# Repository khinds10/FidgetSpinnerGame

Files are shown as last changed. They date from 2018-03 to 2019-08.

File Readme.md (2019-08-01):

# Fidget Spinner Game - Cool Fidget Spinner Game for my son's Science Fair
Kids love this one, who can spin the longest?  Who can spin the fastest? Find out using this project!

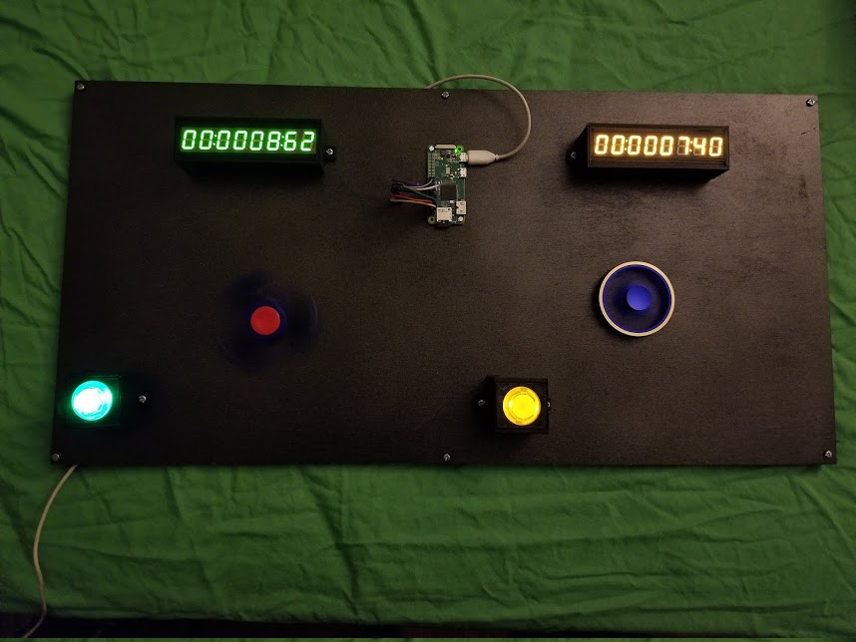
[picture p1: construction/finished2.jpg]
Finished


#### Flashing RaspberriPi Hard Disk / Install Required Software (Using Ubuntu Linux)

Download "RASPBIAN JESSIE LITE"
https://www.raspberrypi.org/downloads/raspbian/

**Create your new hard disk for Fidget Spinner Game**
>Insert the microSD to your computer via USB adapter and create the disk image using the `dd` command
>
> Locate your inserted microSD card via the `df -h` command, unmount it and create the disk image with the disk copy `dd` command
> 
> $ `df -h`
> */dev/sdb1       7.4G   32K  7.4G   1% /media/XXX/1234-5678*
> 
> $ `umount /dev/sdb1`
> 
> **Caution: be sure the command is completely accurate, you can damage other disks with this command**
> 
> *if=location of RASPBIAN JESSIE LITE image file*
> *of=location of your microSD card*
> 
> $ `sudo dd bs=4M if=/path/to/raspbian-jessie-lite.img of=/dev/sdb`
> *(note: in this case, it's /dev/sdb, /dev/sdb1 was an existing factory partition on the microSD)*

**Setting up your RaspberriPi**

*Insert your new microSD card to the raspberrypi and power it on with a monitor connected to the HDMI port*

Login
> user: **pi**
>
> pass: **raspberry**

Change your account password for security
>`sudo passwd pi`

Enable RaspberriPi Advanced Options
>`sudo raspi-config`

Choose:
`1 Expand File System`

`9 Advanced Options`
>`A2 Hostname`
>*change it to "FidgetSpinner"*
>
>`A4 SSH`
>*Enable SSH Server*
>
>`A7 I2C`
>*Enable i2c interface*

**Enable the English/US Keyboard**

>`sudo nano /etc/default/keyboard`

> Change the following line:
>`XKBLAYOUT="us"`

**Reboot PI for Keyboard layout changes / file system resizing to take effect**
>$ `sudo shutdown -r now`

**Auto-Connect to your WiFi**

>`sudo nano /etc/wpa_supplicant/wpa_supplicant.conf`

Add the following lines to have your raspberrypi automatically connect to your home WiFi
*(if your wireless network is named "linksys" for example, in the following example)*

	network={
	   ssid="linksys"
	   psk="WIRELESS PASSWORD HERE"
	}

**Reboot PI to connect to WiFi network**

>$ `sudo shutdown -r now`
>
>Now that your PI is finally on the local network, you can login remotely to it via SSH.
>But first you need to get the IP address it currently has.
>
>$ `ifconfig`
>*Look for "inet addr: 192.168.XXX.XXX" in the following command's output for your PI's IP Address*

**Go to another machine and login to your raspberrypi via ssh**

> $ `ssh pi@192.168.XXX.XXX`

**Start Installing required packages**

>$ `sudo apt-get update`
>
>$ `sudo apt-get upgrade`
>
>$ `sudo apt-get install memcached vim git python-smbus i2c-tools python-imaging python-smbus build-essential python-dev rpi.gpio python3 python3-pip python-memcache python-gpiozero python-psutil`

**Update local timezone settings

>$ `sudo dpkg-reconfigure tzdata`

`select your timezone using the interface`

**Setup the simple directory `l` command [optional]**

>`vi ~/.bashrc`
>
>*add the following line:*
>
>`alias l='ls -lh'`
>
>`source ~/.bashrc`

**Fix VIM default syntax highlighting [optional]**

>`sudo vi  /etc/vim/vimrc`
>
>uncomment the following line:
>
>_syntax on_

**Clone Game repository**

>$ `cd ~`
>
>$ `git clone https://github.com/khinds10/FidgetSpinnerGame.git`

**Install i2c Backpack Python Drivers**

>$ `cd ~`
>
>$ `git clone https://github.com/adafruit/Adafruit_Python_LED_Backpack`
>
>$ `cd Adafruit_Python_LED_Backpack/`
>
>$ `sudo python setup.py install`
>

### Setup the scripts to run at boot
`crontab -e`

Add the following lines:

> `@reboot /bin/sleep 20; /usr/bin/python /home/pi/FidgetSpinnerGame/player1.py`
>
> `@reboot /bin/sleep 25; /usr/bin/python /home/pi/FidgetSpinnerGame/player2.py`
>
> `@reboot /bin/sleep 15; /usr/bin/python /home/pi/FidgetSpinnerGame/select.py`
>

### Supplies Needed

For the below supplies list I went with yellow vs green for team colors, however you can pick, red vs blue etc.

**Small thin sheet of plywood**

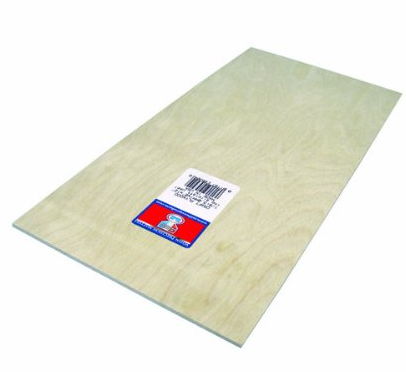
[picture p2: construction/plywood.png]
Plywood


**RaspberriPi Zero**

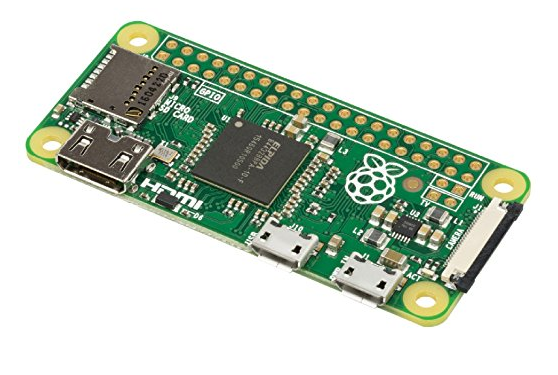
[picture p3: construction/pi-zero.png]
Pi Zero


**LED Illuminated Push button Built-in Switch 5V Button (yellow / green)**

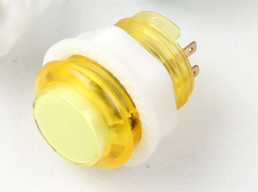
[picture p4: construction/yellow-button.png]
Yellow LED Illuminated Button


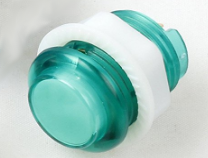
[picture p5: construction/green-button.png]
Green LED Illuminated Button


**7-segment Display W/i2c Backpack (yellow)**

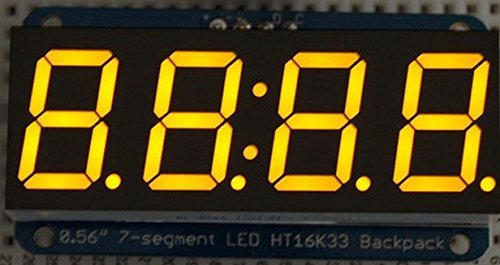
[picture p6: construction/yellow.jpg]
Yellow Display


**7-segment Display W/i2c Backpack (green)**

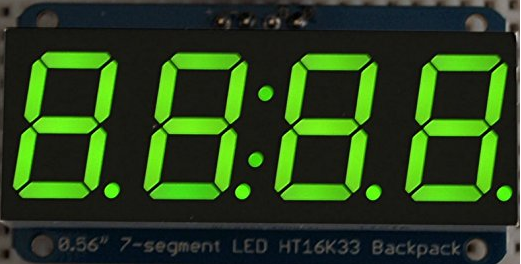
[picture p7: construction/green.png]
Green Display


## Preparing Hardware

Solder Unique Display Jumpers
*NOTE: All the I2C backpacks must be soldered on the back of each of the displays, the backpacks come with the display and must all be soldered on first.*

For each of the I2C backpack displays you must solder the jumpers on the back in the **4 different possible combinations** to have your RaspberriPI I2C interface to recognize each display with a **unique address**.  

Leave the first display with no jumper soldered, the 2nd with the farthest right soldered, the 3rd with only the middle soldered and so on...  

*There's a total of 3 pins so you should have a total combination of 8 unique combinations.*

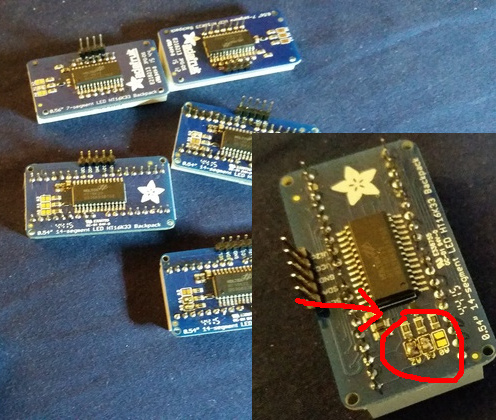
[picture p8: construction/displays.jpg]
Solder Unique Display Jumpers


### Wiring Diagram

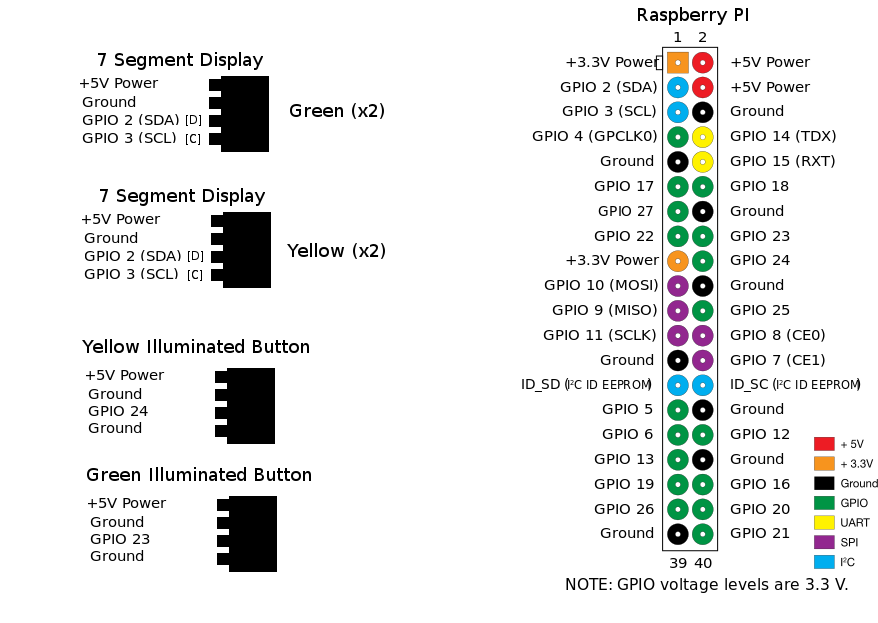
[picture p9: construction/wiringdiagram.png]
Wiring Diagram


### Test 7 Segment Display I2C Connectivity

Start up your RaspberryPi and make sure the I2C bus recognizes all your connected 7 segment displays. 
*[each display is given a unique address described above by how you solder each display's jumpers in different combinations]*

If you have all 4 displays with jumpers soldered in all 4 combinations, you should have the following output for the `i2cdetect` command:

`sudo i2cdetect -y 1`
     
>    0  1  2  3  4  5  6  7  8  9  a  b  c  d  e  f
>
> 00:          -- -- -- -- -- -- -- -- -- -- -- -- -- 
> 
> 10: -- -- -- -- -- -- -- -- -- -- -- -- -- -- -- -- 
> 
> 20: -- -- -- -- -- -- -- -- -- -- -- -- -- -- -- -- 
> 
> 30: -- -- -- -- -- -- -- -- -- -- -- -- -- -- -- -- 
> 
> 40: -- -- -- -- -- -- -- -- -- -- -- -- -- -- -- -- 
> 
> 50: -- -- -- -- -- -- -- -- -- -- -- -- -- -- -- -- 
> 
> 60: -- -- -- -- -- -- -- -- -- -- -- -- -- -- -- -- 
> 
> 70: 70 71 72 73 -- -- -- --

*(in this case all the displays numbered 0 to 4 are being recognized on the PI as I2C available devices)*

### Building the Game

Using a 3d printer and the provided (.stl) files in the /enclosure folder of this project print the button and display cases and the 6 small squares used to attach to the bottom of the plywood to hold the game board slightly off the table for wiring.

Paint the board to mount the button, RaspberriPi and 7 Seg. Displays

Paint Board

Connect the Displays and buttons accordingly with wired leads

Wire Displays & Buttons

Gather Parts to assemble on the board, drill holes where the wires will be feed through below to connect everything

Gather Parts

Wire the Board from below, feeding the wires through the drilled holes in the board

Wire the Board

Mount/Connect the RaspberriPi to the correct leads

Connect RPi

### Finished!

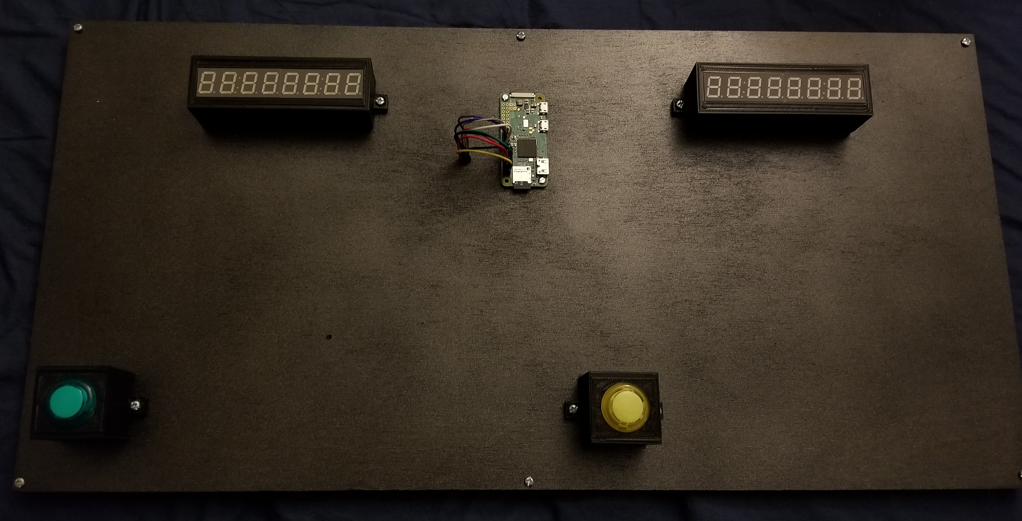
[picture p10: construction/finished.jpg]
Finished

Finished

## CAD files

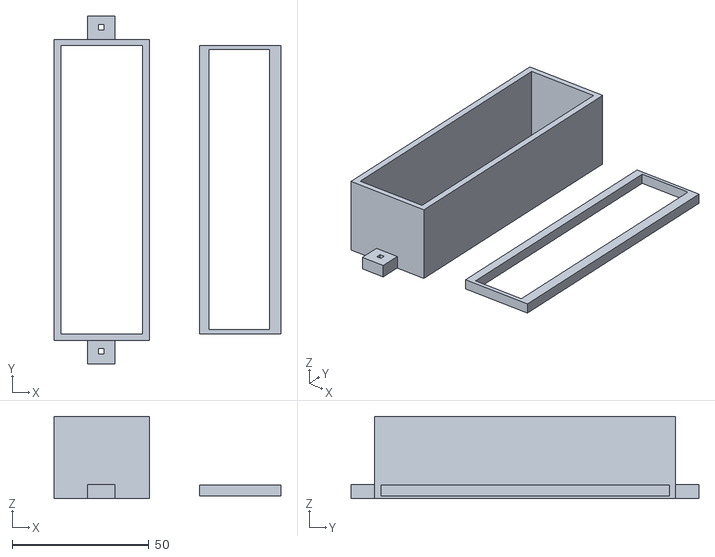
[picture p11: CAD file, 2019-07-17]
enclosure/LEDAlphaNum.stl
83.0 x 127.3 x 30.0

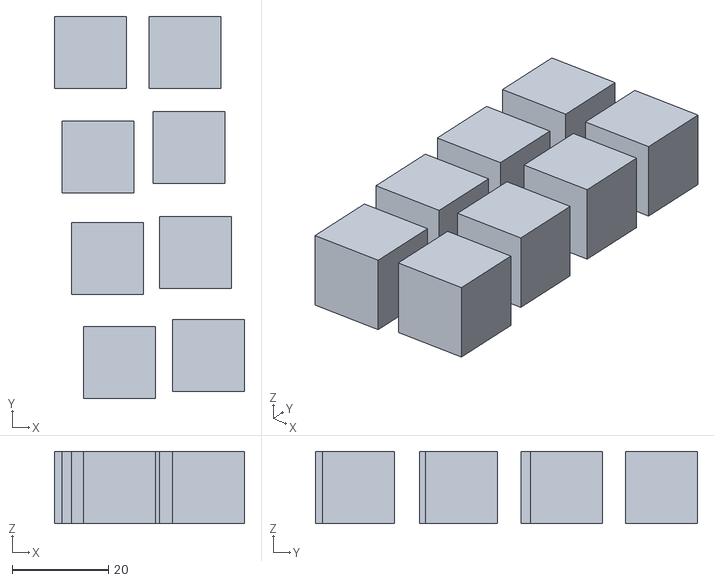
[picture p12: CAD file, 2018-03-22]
enclosure/LEDDisplay-Final-Mounts.stl
39.6 x 79.7 x 15.0

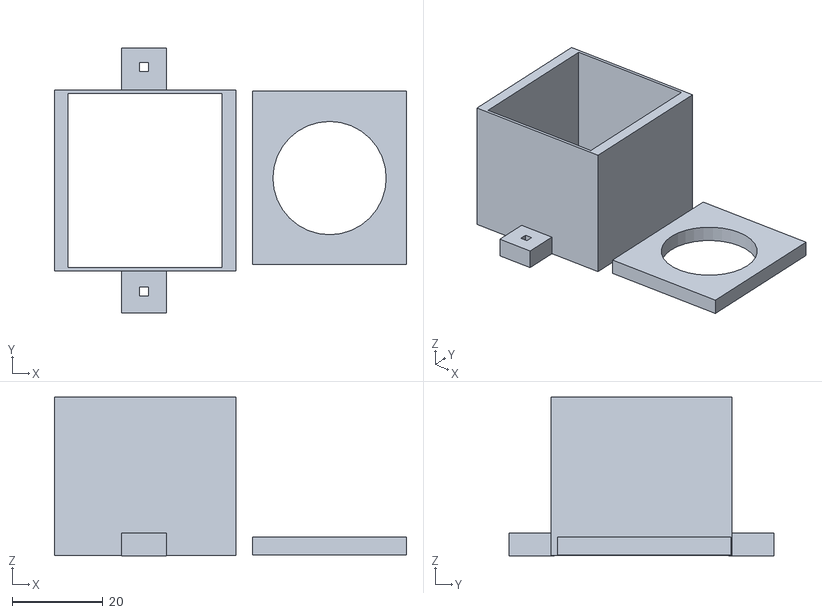
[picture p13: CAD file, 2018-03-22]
enclosure/LEDDisplay-Button-Container-Final.stl
77.7 x 58.4 x 35.0

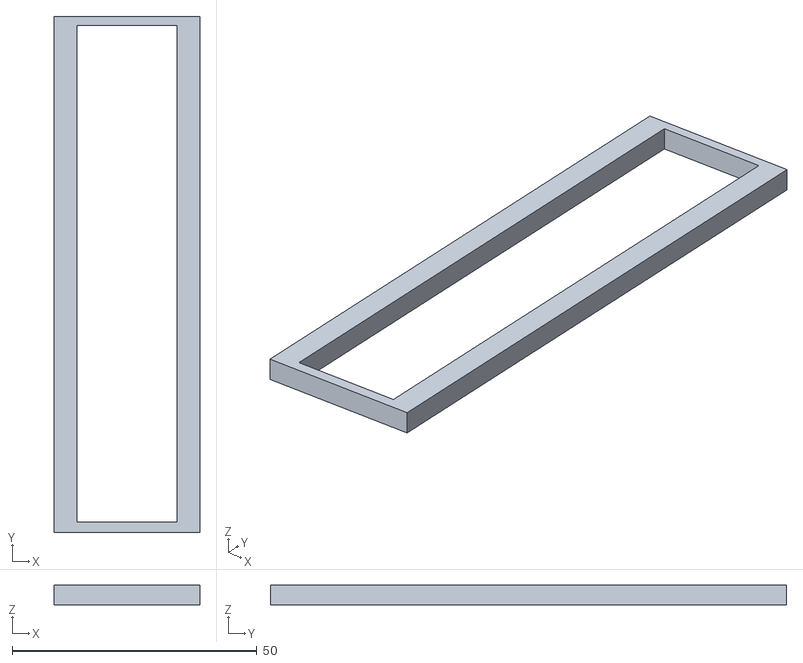
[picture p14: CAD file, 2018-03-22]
enclosure/LEDDisplay-Frame-Final.stl
29.8 x 105.5 x 4.00

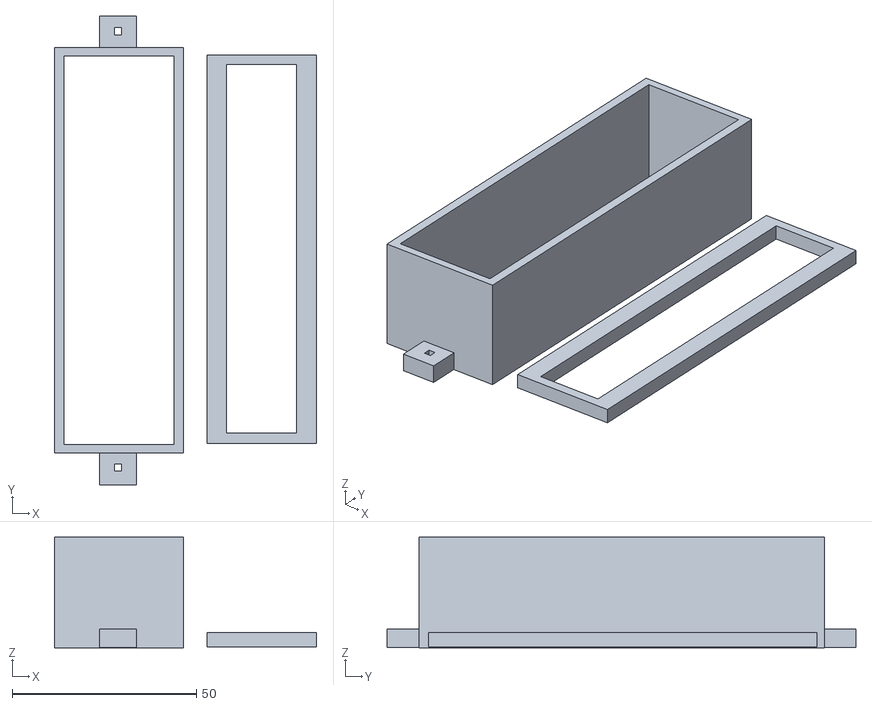
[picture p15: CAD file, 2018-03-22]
enclosure/LEDDisplay-Container-Final.stl
71.1 x 127.3 x 30.0

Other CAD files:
enclosure/LEDDisplay-Frame-Final2.stl
enclosure/LEDAlphaNum.blend
enclosure/LEDDisplay-Button-Container-Final.blend
enclosure/LEDDisplay-Button-Container.blend
enclosure/LEDDisplay-Container-Alpha.blend
enclosure/LEDDisplay-Container-Final.blend
enclosure/LEDDisplay-Container.blend
enclosure/LEDDisplay-Final-Frame.blend
enclosure/LEDDisplay-Final-Mounts.blend
enclosure/LEDDisplay-Final.blend
enclosure/LEDDisplay.blend

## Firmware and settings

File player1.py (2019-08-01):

#! /usr/bin/python
# player script to listen for button press, then start the timer or scoreboard
# Kevin Hinds http://www.kevinhinds.com
# License: GPL 2.0

import time, datetime, sys, json, string, cgi, subprocess, json, datetime, memcache
import os, signal, atexit, psutil
import subprocess
from gpiozero import Button
from Adafruit_LED_Backpack import SevenSegment
mc = memcache.Client(['127.0.0.1:11211'], debug=0)

playerMinutes = SevenSegment.SevenSegment(address=0x74)
playerMinutes.begin()
playerMinutes.clear()
playerMinutes.write_display()

playerSeconds = SevenSegment.SevenSegment(address=0x70)
playerSeconds.begin()
playerSeconds.clear()
playerSeconds.write_display()

def clearDisplay():
    """setup the display and begin the display starting from zero"""
    global minutesOutputPrevious
    global startTime
    global milleseconds
    
    minutesOutputPrevious = ''
    startTime = 0
    milleseconds = 0
    
    playerMinutes.set_colon(True)
    playerMinutes.write_display()
    playerSeconds.set_colon(True)
    playerSeconds.write_display()

    zeroChars = [0,0,0,0]
    count = 0
    while (count < 4):
        playerMinutes.set_digit(count, zeroChars[count])
        playerSeconds.set_digit(count, zeroChars[count])
        count = count + 1
    playerMinutes.write_display()
    playerSeconds.write_display()
    
def runTimer():
    """run the timer showing number of seconds on the 7 segment display"""
    global minutesOutputPrevious
    global startTime
    global milleseconds
    while True:

        # from the start of the script, get the time in seconds, milleseconds to display
        if (startTime == 0):
            startTime = time.time()
        elapsedTime = time.time() - startTime
            
        # write the 4 digits individually to the display, but only if they've changed
        minutesOutput = str(time.strftime("%H%M", time.gmtime(elapsedTime)))
        if minutesOutputPrevious != minutesOutput:
            count = 0
            minutesOutputChars = list(minutesOutput)
            while (count < 4):
                playerMinutes.set_digit(count, minutesOutput[count])
                count = count + 1
            playerMinutes.write_display()
            minutesOutputPrevious = minutesOutput
        
        # keep track of hypothetical milleseconds (they won't be 100% accurate based on script speed)
        milleseconds = milleseconds + 1
        if milleseconds > 99: 
            milleseconds = 1 
        secondsOutput = str(time.strftime("%S", time.gmtime(elapsedTime))) + str('%02d' % milleseconds)
        
        # write the 4 digits individually to the display
        count = 0
        secondsOutputChars = list(secondsOutput)
        while (count < 4):
            playerSeconds.set_digit(count, secondsOutputChars[count])
            count = count + 1
        playerSeconds.write_display()

timerState = 0
processId = False
def timer():
    global timerState
    global processId
    
    if timerState == 0:
        processId = os.fork()
        if processId == 0:
            runTimer()
            
    if timerState == 1:
        if processId > 0:
            os.kill(processId, signal.SIGKILL)
    
    if timerState == 2:
        clearDisplay()        
    timerState = timerState + 1
    if timerState > 2:
        timerState = 0

def setScore(score):
    """set the score int to the display"""
    playerSeconds.clear()
    count = 0
    while (count < 4):
        playerMinutes.set_digit(count, " ")
        count = count + 1
    playerMinutes.set_colon(False)
    playerMinutes.write_display()    
    playerSeconds.print_float(int(score), decimal_digits=0)
    playerSeconds.write_display()

def score():
    playerScore = mc.get("PLAYER1")
    playerScore = playerScore + 1
    mc.set("PLAYER1", playerScore)
    setScore(playerScore)

def clear():
    mc.set("PLAYER1", -1)
    clearDisplay()
    
button = Button(24)
clearDisplay()
while True:
    scoreBoardType = mc.get("TYPE")
    if (scoreBoardType == "SCORE"):
        button.when_pressed = score
        
    elif (scoreBoardType == "TIMER"):
        button.when_pressed = timer
        
    elif (scoreBoardType == "CLEAR"):
        button.when_pressed = clear

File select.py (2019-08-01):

#! /usr/bin/python
# player script to listen for select score board "type" button press
# Kevin Hinds http://www.kevinhinds.com
# License: GPL 2.0
import sys, time, json, string, cgi, subprocess, json, datetime, memcache
from gpiozero import Button
from Adafruit_LED_Backpack import AlphaNum4
mc = memcache.Client(['127.0.0.1:11211'], debug=0)

# setup the alphanumeric displays
displayOne = AlphaNum4.AlphaNum4(address=0x77)
displayOne.begin()
displayOne.set_brightness(8)
displayOne.clear()

displayTwo = AlphaNum4.AlphaNum4(address=0x76)
displayTwo.begin()
displayTwo.set_brightness(8)
displayTwo.clear()

def displayType(scoreBoardType):
    """set the ALPHNUM to scoreBoardType string value, with some padded spaces"""
    scoreBoardType = str(scoreBoardType)
    scoreBoardType = " " + scoreBoardType + "  "
    
    displayOne.clear()
    displayOne.print_str(scoreBoardType[0:4])
    displayOne.write_display()
    
    displayTwo.clear()
    displayTwo.print_str(scoreBoardType[4:8])
    displayTwo.write_display()

def select():
    """based on current game selected """
    scoreBoardType = mc.get("TYPE")

    if (scoreBoardType == "SCORE"):
        scoreBoardType = "TIMER"

    elif (scoreBoardType == "TIMER"):
        scoreBoardType = "CLEAR"

    elif (scoreBoardType == "CLEAR"):
        scoreBoardType = "SCORE"

    elif (scoreBoardType == "None"):
        scoreBoardType = "SCORE"

    mc.set("TYPE", scoreBoardType)
    displayType(scoreBoardType)
    

# set up defaults and show on alphanumeric display
mc.set("TYPE", "SCORE")
mc.set("PLAYER1", -1)
mc.set("PLAYER2", -1)

scoreBoardType = mc.get("TYPE")
displayType(scoreBoardType)

button = Button(17)
select()
while True:
    button.when_pressed = select

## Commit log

2018-03-22 added project files
    [LEDDisplay-Button-Container-Final.blend, LEDDisplay-Button-Container-Final.stl, LEDDisplay-Button-Container.blend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]
2019-07-17 added new alpha display container
    [LEDAlphaNum.blend, LEDAlphaNum.stl, LEDDisplay-Container-Alpha.blend]
2019-08-01 update to resolve conflict
    [player1.py, player2.py, select.py]
